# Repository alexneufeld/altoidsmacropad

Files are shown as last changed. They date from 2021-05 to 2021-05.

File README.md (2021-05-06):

# 12 Key Altoids Tin MacroPad

By Alex Neufeld, 2021

### Features:
- 12 cherry style mechanical keyswitches
- Custom PCB
- QMK firmware via a Sparkfun Pro Micro clone

### Building

The design files as available in this repo. I don't have a formal build guide, sorry. 

If you just want to get some PCBs made, there is a gerber .zip file in the `pcb` directory.

I cut the top of the case with a cutoff wheel in a rotary tool. There is a printable template in the `case` directory that I attached with spray adhesive and cut through.

Quick note on the firmware side of things: QMK is very new to me. the `firmware` directory has a proof of concept fileset that was enough to get a basic keymap onto my board. You're on your own if you want to add fancier features (layers, etc.) 

### BOM

| Part | Quantity | Example source |
|---|---|---|
| Case | 1 | [LINK](https://www.amazon.com/dp/B07GG67NNH/) |
| Switches  | 12 | [LINK](https://www.aliexpress.com/item/32862816873.html) |
| Keycaps | 12 | [LINK](https://www.aliexpress.com/item/32830177884.html) |
| Pro Micro | 1 | [LINK](https://www.aliexpress.com/item/32768308647.html) |
| Diodes | 12 | [LINK](https://www.digikey.ca/short/m5v7m70m) |

### Gallery

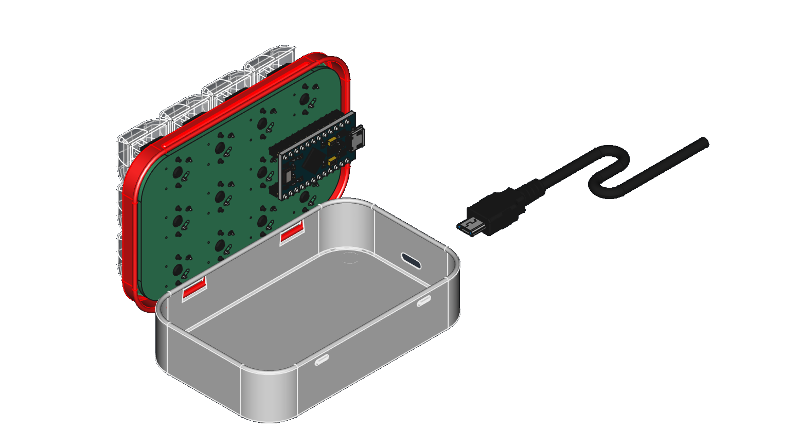
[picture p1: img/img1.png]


CAD design



3D printed plate, the mint tin sheet metal is too thin to securely hold the switches.

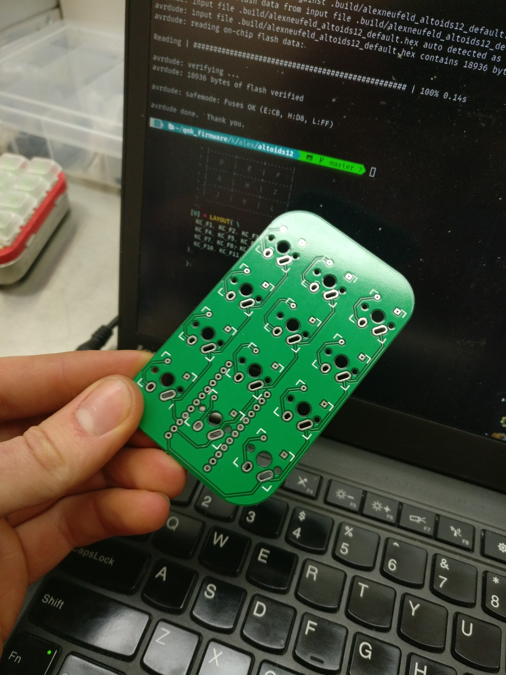
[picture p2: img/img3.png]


PCB ready to go.



Testing with the Pro-Micro clone.



Upper assembly soldered and ready.



Add felt pads to the bottom of the case.



Steel plate for inertia, kapton tape to insulate the electronics from contact with metal parts.



Finished! rear view with cutout for USB-in.

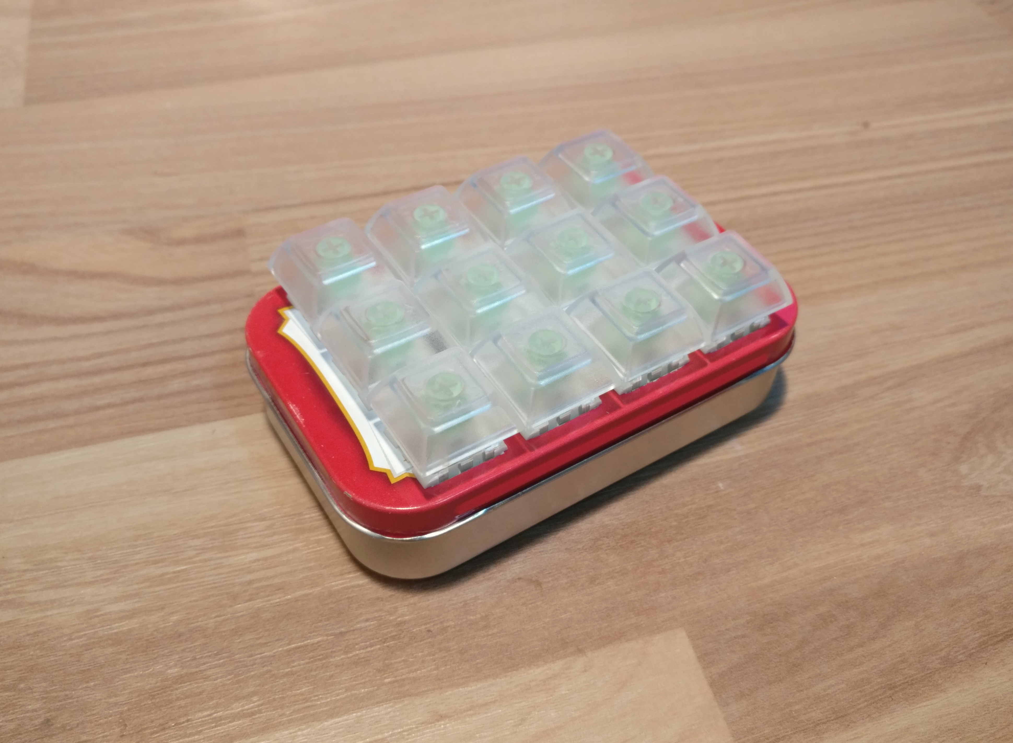
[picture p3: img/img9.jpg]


Kailh box jade switches and clear, blank PBT keycaps installed.

### Schematic



## Acknowledgments

This project was inspired in part by the [2% milk keyboard.](https://github.com/Spaceman/SpaceboardsHardware/tree/master/Keyboards/2%25%20Milk)

Ruiqi Mao's [Keyboard PCB guide](https://github.com/ruiqimao/keyboard-pcb-guide#production) was very helpful.

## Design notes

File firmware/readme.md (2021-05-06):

# The Altoids Macropad

A 12-key macropad that uses a common mint candy container as a case

By Alex Neufeld, 2021

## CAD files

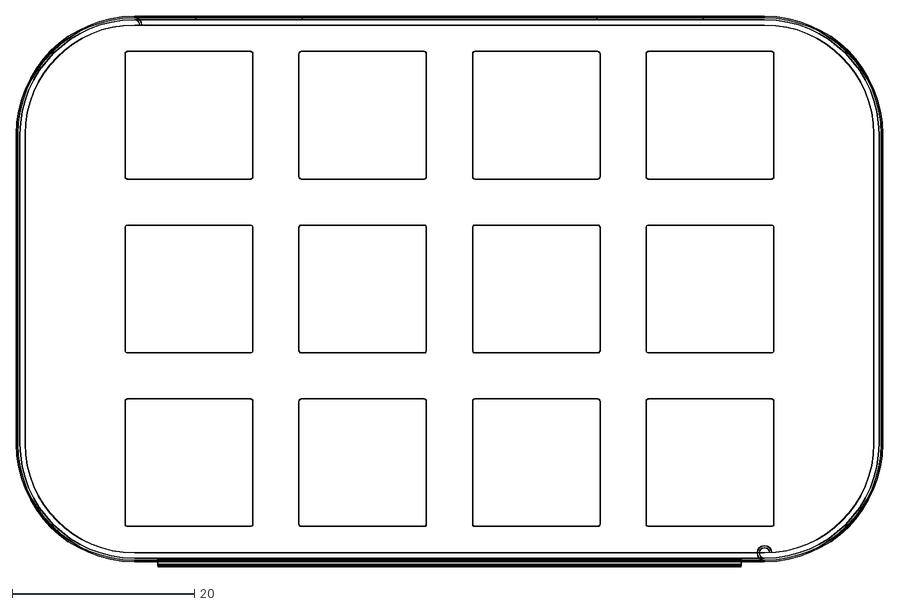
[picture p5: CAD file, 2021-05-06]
case/altoids_macropad-lid_cut_template.dxf
95.0 x 60.4

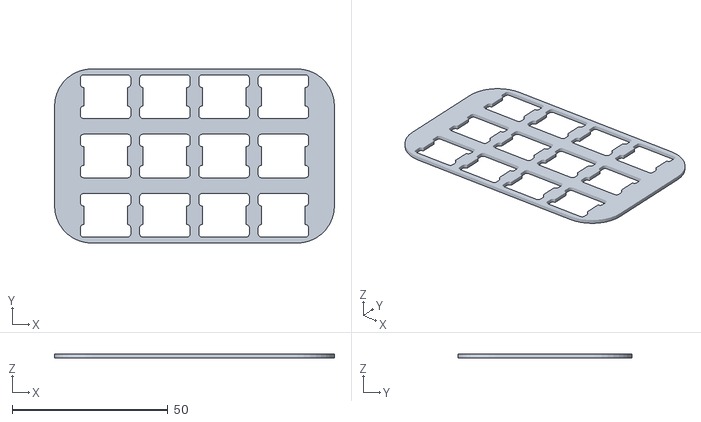
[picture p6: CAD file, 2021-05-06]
case/altoids_macropad-Plate_PCB.stl
90.0 x 56.0 x 1.30

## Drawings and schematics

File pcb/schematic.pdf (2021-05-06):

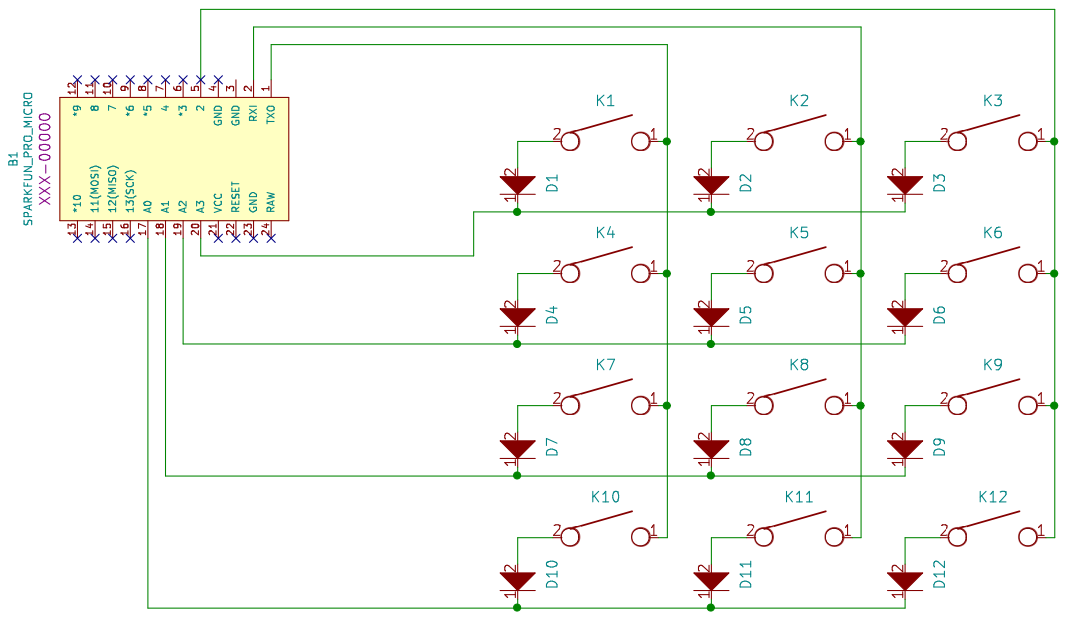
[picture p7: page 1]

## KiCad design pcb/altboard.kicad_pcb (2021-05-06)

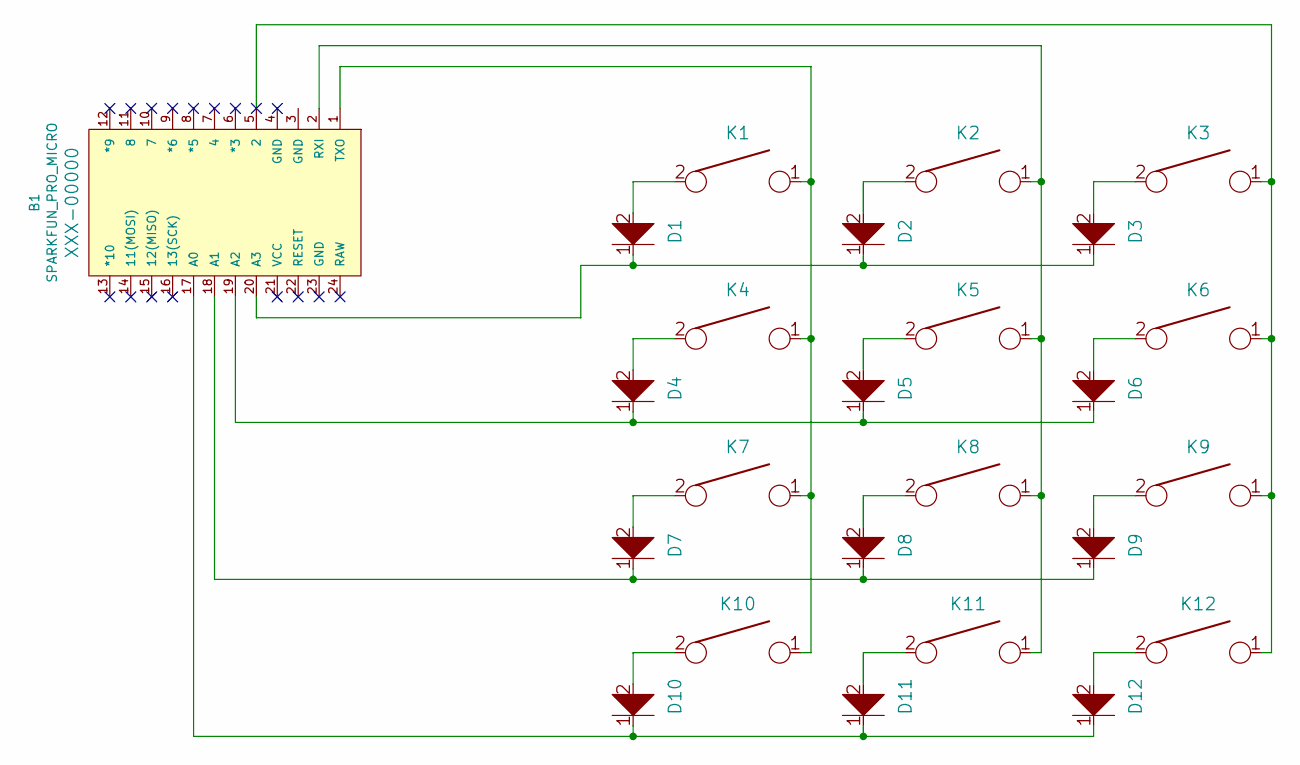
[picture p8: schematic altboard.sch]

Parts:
B1: SPARKFUN_PRO_MICRO
D1, D2, D3, D4, D5, D6, D7, D8, D9, D10, D11, D12: D; D_SOD123_axial
K1, K2, K3, K4, K5, K6, K7, K8, K9, K10, K11, K12: KEYSW; Mx_Alps_100

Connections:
unnamed: B1.1 (TXO), K1.1, K4.1, K7.1, K10.1
unnamed: B1.2 (RXI), K2.1, K5.1, K8.1, K11.1
unnamed: B1.5 (2), K3.1, K6.1, K9.1, K12.1
unnamed: B1.17 (A0), D10.1, D11.1, D12.1
unnamed: B1.18 (A1), D7.1, D8.1, D9.1
unnamed: B1.19 (A2), D4.1, D5.1, D6.1
unnamed: B1.20 (A3), D1.1, D2.1, D3.1
unnamed: D1.2, K1.2
unnamed: D2.2, K2.2
unnamed: D3.2, K3.2
unnamed: D4.2, K4.2
unnamed: D5.2, K5.2
unnamed: D6.2, K6.2
unnamed: D7.2, K7.2
unnamed: D8.2, K8.2
unnamed: D9.2, K9.2
unnamed: D10.2, K10.2
unnamed: D11.2, K11.2
unnamed: D12.2, K12.2

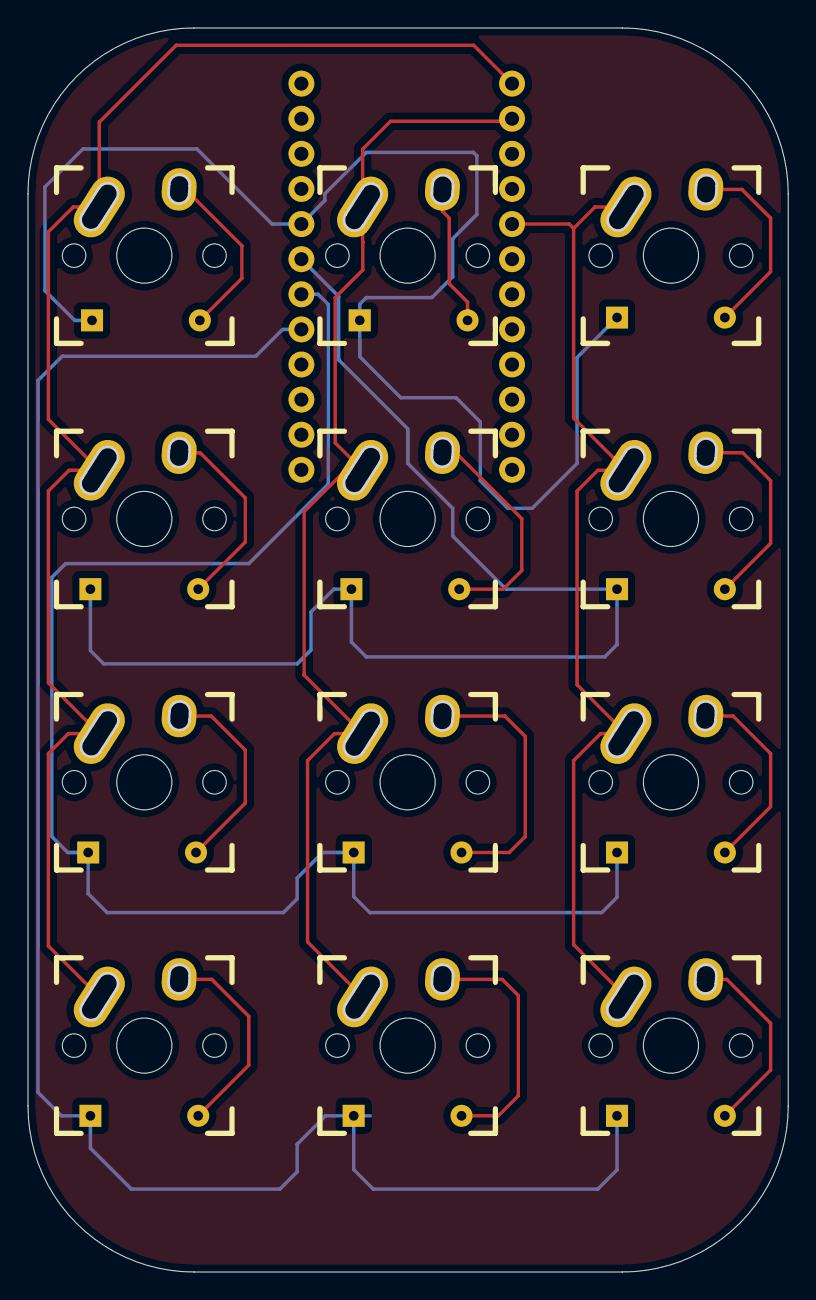
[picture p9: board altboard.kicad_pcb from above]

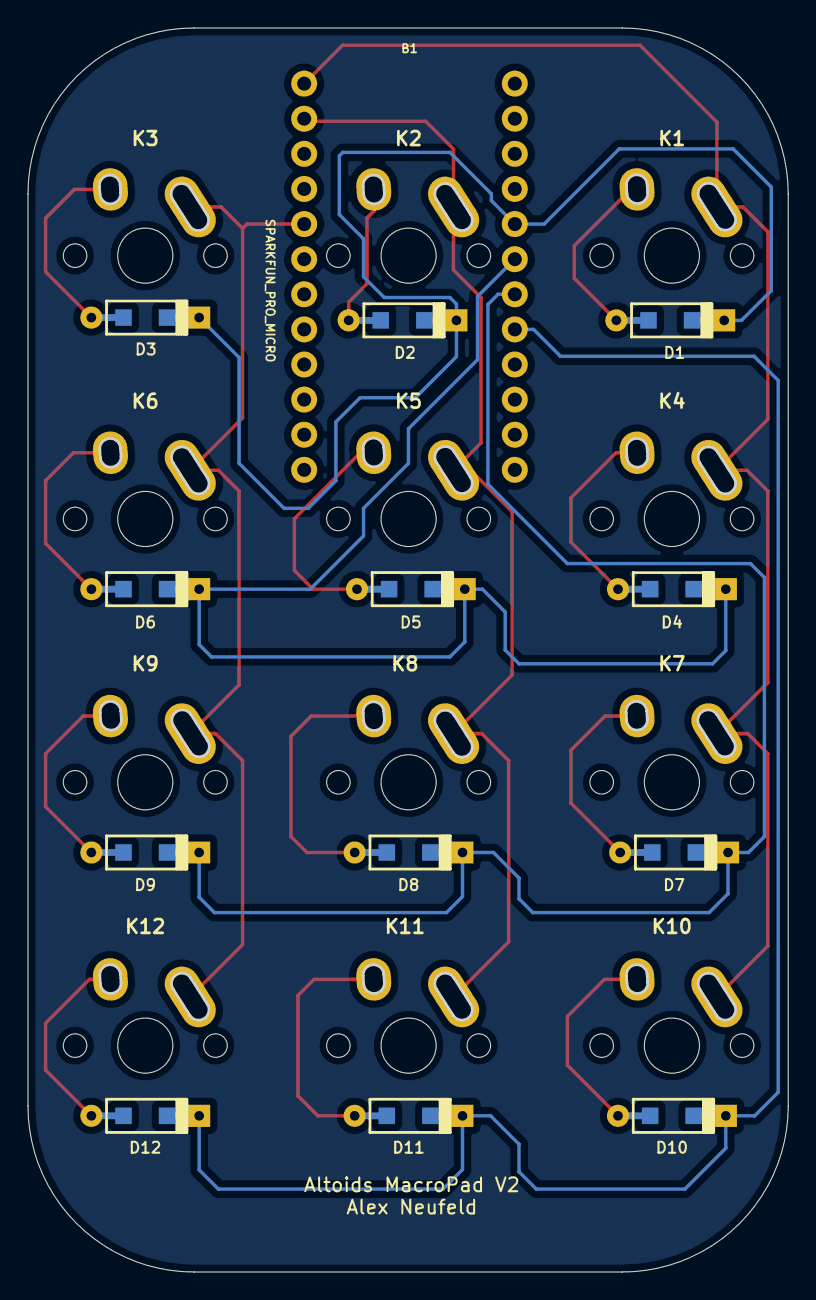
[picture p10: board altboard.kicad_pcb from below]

Board: 2 copper layers, 55.0 x 90.0 mm, 25 parts (13 on the bottom side), 19 nets.
